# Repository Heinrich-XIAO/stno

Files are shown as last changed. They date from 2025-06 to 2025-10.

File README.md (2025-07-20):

# stno

stno is a one-handed steno keyboard with joysticks for my thumb. I wanted to make stno because I became obsessed with steno, didn't have an n-key roll over keyboard and i didnt want to keep arpegiating, and i wanted a one-handed keyboard like my other keyboards (all of them were too small for a steno layout). I wanted to use joysticks since i feel like holding two keys with one finger is awkward and wanted to minimize it, especially for the thumb.

## 🟩PCB
1751285202-wayshot

## 📐Schematic
1751285280-wayshot

## 📏CAD




## 📦BOM

| Name | Price (and Currency) | Link/source | Notes |
|---|---|---|---|
| Springs | $13.49 CAD | https://www.aliexpress.com/item/1005006171011050.html | $4.52 after welcome deal |
| TTC Neptune Switches | $27.26 USD | https://milktooth.com/products/neptune | $5.09 per pack $11.99 shipping |
| Arduino Nano ESP32 | $29.67 USD | https://store-usa.arduino.cc/products/nano-esp32 | |
| Joysticks | $21.67 CAD | https://www.amazon.com/PS5-Hall-Effect-Joystick-Replacement-2-Pack/dp/B0DN8T9KJW | $7.68 shipping + $13.99 |
| Thumbscrews | $13.99 CAD | https://www.amazon.ca/MECCANIXITY-Stainless-Thumbscrew-Appliances-Electronic/dp/B0F282TJ7D | |
| Nuts and Bolts | $13.11 CAD | https://www.amazon.ca/Walfront-Socket-Head-Button-Screws/dp/B0742DDLQ1 | this is an assortment of screws but its still somehow cheaper than some non-assortements ive found. it also means hackclub won't have to pay for 10 dollars worth of bolts every time i need a different length of bolt |
| Keycaps | $5.31 CAD | https://www.aliexpress.com/item/1005008653485944.html | 3 packs of ten $1.36 per pack |
| Heatset Inserts | $4.79 CAD | https://www.aliexpress.com/item/1005003582355741.html | m3 4mm $1.39 after welcome deal |
| Hotswap Sockets | $9.83 CAD | https://www.aliexpress.com/item/1005003913466247.html | $1.39 after welcome deal |
| PCB | $31.82 USD | JLCPCB | 

Total: $145.99 USD

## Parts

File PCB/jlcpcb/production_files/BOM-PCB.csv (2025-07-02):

Comment | Designator | Footprint | LCSC | Quantity
SK6812 | D41 | LED_SK6812_PLCC4_5.0x5.0mm_P3.2mm |  | 1
1N4148 | D5 | DIOAD753W49L380D172B |  | 1
1N4148 | D3 | DIOAD753W49L380D172B |  | 1
1N4148 | D1 | DIOAD753W49L380D172B |  | 1
1N4148 | D2 | DIOAD753W49L380D172B |  | 1
1N4148 | D18 | DIOAD753W49L380D172B |  | 1
1N4148 | D14 | DIOAD753W49L380D172B |  | 1
SK6812 | D33 | LED_SK6812_PLCC4_5.0x5.0mm_P3.2mm |  | 1
SK6812 | D31 | LED_SK6812_PLCC4_5.0x5.0mm_P3.2mm |  | 1
COM-09032 | U1 | PS4_joystick |  | 1
Arduino_Nano_ESP32 | A1 | Arduino_Nano |  | 1
SK6812 | D35 | LED_SK6812_PLCC4_5.0x5.0mm_P3.2mm |  | 1
1N4148 | D4 | DIOAD753W49L380D172B |  | 1
1N4148 | D8 | DIOAD753W49L380D172B |  | 1
1N4148 | D13 | DIOAD753W49L380D172B |  | 1
SK6812 | D34 | LED_SK6812_PLCC4_5.0x5.0mm_P3.2mm |  | 1
SK6812 | D46 | LED_SK6812_PLCC4_5.0x5.0mm_P3.2mm |  | 1
SK6812 | D37 | LED_SK6812_PLCC4_5.0x5.0mm_P3.2mm |  | 1
SK6812 | D40 | LED_SK6812_PLCC4_5.0x5.0mm_P3.2mm |  | 1
1N4148 | D10 | DIOAD753W49L380D172B |  | 1
SK6812 | D50 | LED_SK6812_PLCC4_5.0x5.0mm_P3.2mm |  | 1
1N4148 | D23 | DIOAD753W49L380D172B |  | 1
SK6812 | D38 | LED_SK6812_PLCC4_5.0x5.0mm_P3.2mm |  | 1
SK6812 | D47 | LED_SK6812_PLCC4_5.0x5.0mm_P3.2mm |  | 1
1N4148 | D19 | DIOAD753W49L380D172B |  | 1
SK6812 | D45 | LED_SK6812_PLCC4_5.0x5.0mm_P3.2mm |  | 1
1N4148 | D20 | DIOAD753W49L380D172B |  | 1
1N4148 | D21 | DIOAD753W49L380D172B |  | 1
SK6812 | D29 | LED_SK6812_PLCC4_5.0x5.0mm_P3.2mm |  | 1
1N4148 | D12 | DIOAD753W49L380D172B |  | 1
1N4148 | D24 | DIOAD753W49L380D172B |  | 1
SK6812 | D32 | LED_SK6812_PLCC4_5.0x5.0mm_P3.2mm |  | 1
SK6812 | D26 | LED_SK6812_PLCC4_5.0x5.0mm_P3.2mm |  | 1
SK6812 | D39 | LED_SK6812_PLCC4_5.0x5.0mm_P3.2mm |  | 1
SK6812 | D28 | LED_SK6812_PLCC4_5.0x5.0mm_P3.2mm |  | 1
SK6812 | D42 | LED_SK6812_PLCC4_5.0x5.0mm_P3.2mm |  | 1
SK6812 | D44 | LED_SK6812_PLCC4_5.0x5.0mm_P3.2mm |  | 1
COM-09032 | U2 | PS4_joystick |  | 1
1N4148 | D11 | DIOAD753W49L380D172B |  | 1
SK6812 | D43 | LED_SK6812_PLCC4_5.0x5.0mm_P3.2mm |  | 1
1N4148 | D15 | DIOAD753W49L380D172B |  | 1
SK6812 | D30 | LED_SK6812_PLCC4_5.0x5.0mm_P3.2mm |  | 1
1N4148 | D9 | DIOAD753W49L380D172B |  | 1
1N4148 | D7 | DIOAD753W49L380D172B |  | 1
SK6812 | D48 | LED_SK6812_PLCC4_5.0x5.0mm_P3.2mm |  | 1
SK6812 | D27 | LED_SK6812_PLCC4_5.0x5.0mm_P3.2mm |  | 1
SK6812 | D36 | LED_SK6812_PLCC4_5.0x5.0mm_P3.2mm |  | 1
SK6812 | D49 | LED_SK6812_PLCC4_5.0x5.0mm_P3.2mm |  | 1
1N4148 | D6 | DIOAD753W49L380D172B |  | 1
1N4148 | D17 | DIOAD753W49L380D172B |  | 1
1N4148 | D25 | DIOAD753W49L380D172B |  | 1
1N4148 | D16 | DIOAD753W49L380D172B |  | 1
1N4148 | D22 | DIOAD753W49L380D172B |  | 1
SW_Push | SW13 | hotswap |  | 1
SW_Push | SW9 | hotswap |  | 1
SW_Push | SW24 | hotswap |  | 1
SW_Push | SW7 | hotswap |  | 1
SW_Push | SW19 | hotswap |  | 1
SW_Push | SW3 | hotswap |  | 1
SW_Push | SW11 | hotswap |  | 1
SW_Push | SW17 | hotswap |  | 1
SW_Push | SW26 | hotswap |  | 1
SW_Push | SW2 | hotswap |  | 1
SW_Push | SW12 | hotswap |  | 1
SW_Push | SW14 | hotswap |  | 1
SW_Push | SW5 | hotswap |  | 1
SW_Push | SW6 | hotswap |  | 1
SW_Push | SW22 | hotswap |  | 1
SW_Push | SW4 | hotswap |  | 1
SW_Push | SW25 | hotswap |  | 1
SW_Push | SW20 | hotswap |  | 1
SW_Push | SW23 | hotswap |  | 1
SW_Push | SW10 | hotswap |  | 1
SW_Push | SW21 | hotswap |  | 1
SW_Push | SW15 | hotswap |  | 1
SW_Push | SW18 | hotswap |  | 1
SW_Push | SW8 | hotswap |  | 1
SW_Push | SW16 | hotswap |  | 1

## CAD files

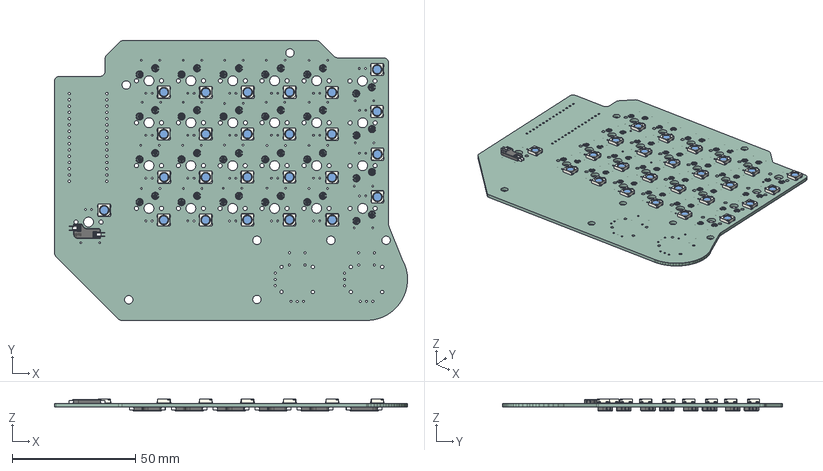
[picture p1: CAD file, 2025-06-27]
PCB/PCB.step
143.2 x 113.5 x 4.88 mm
LED_SK6812_PLCC4_5.0x5.0mm_P3.2mm x 25
Contact x 50
PCB_PCB

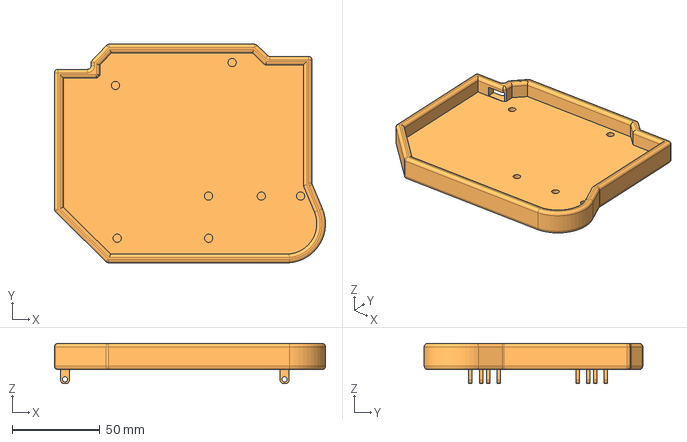
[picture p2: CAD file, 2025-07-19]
production/body.step
154.3 x 124.4 x 23.0 mm

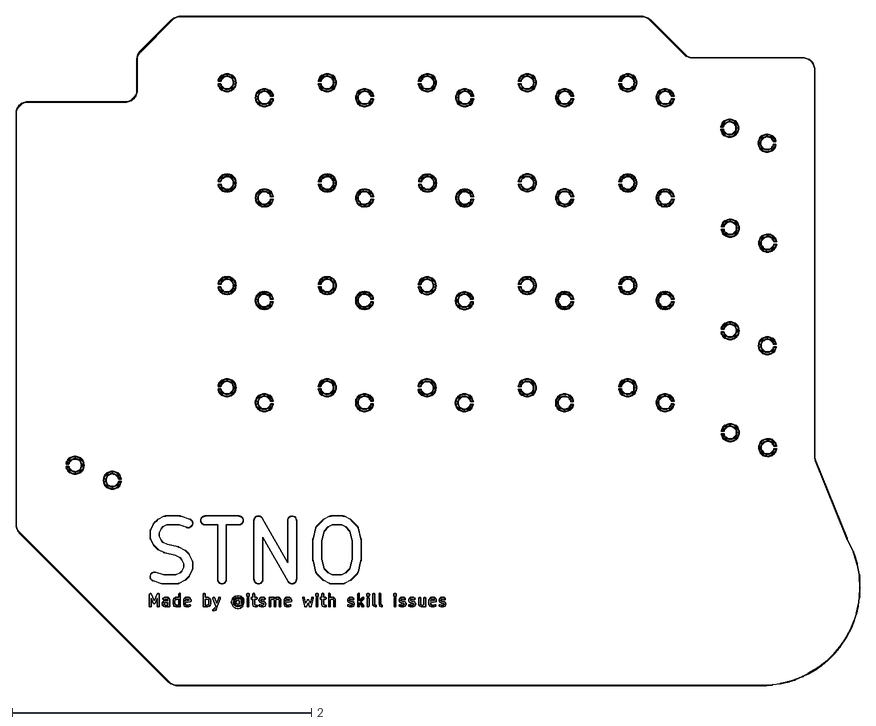
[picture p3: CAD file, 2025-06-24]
PCB/PCB-Edge_Cuts.dxf
5.64 x 4.47

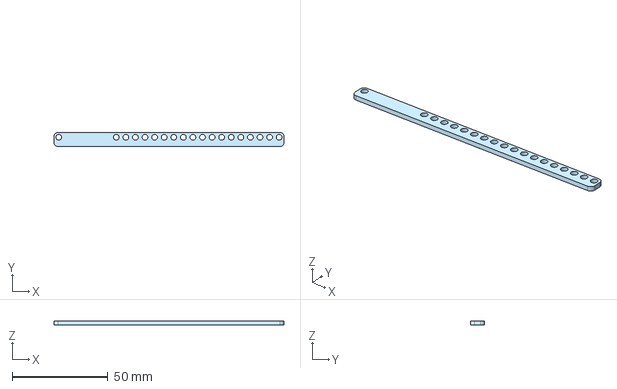
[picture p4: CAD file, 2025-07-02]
production/tent_adjustable_part.step
120.0 x 7.30 x 2.00 mm

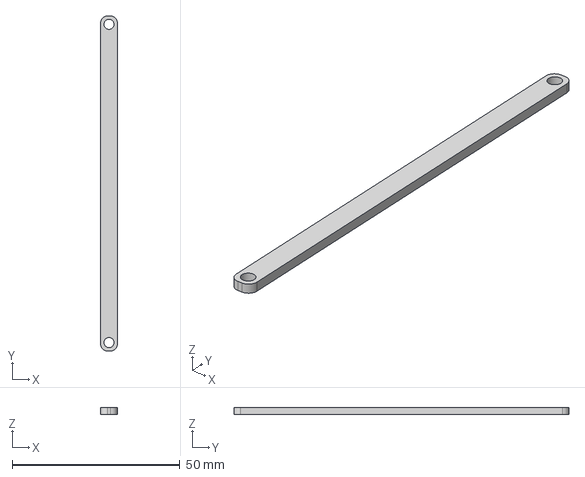
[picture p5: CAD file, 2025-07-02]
production/tent_non_adjustable_part.step
5.00 x 100.0 x 2.00 mm

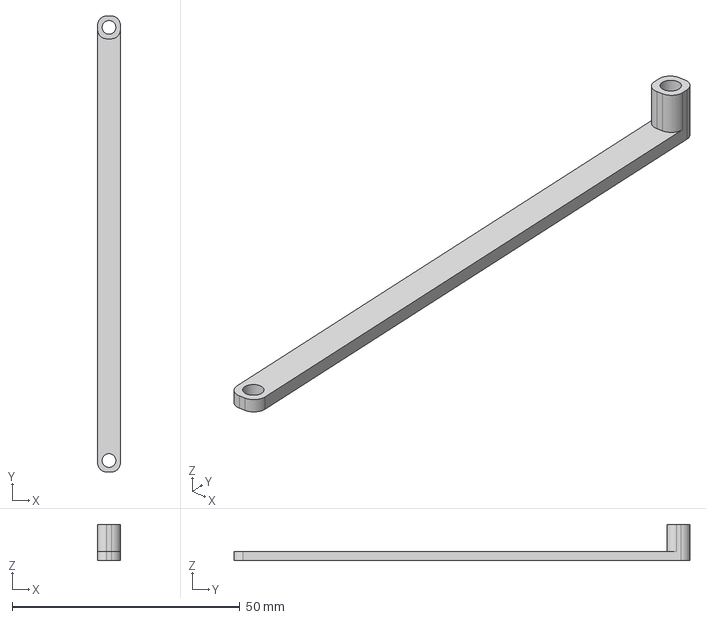
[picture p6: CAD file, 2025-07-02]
production/tent_non_adjustable_with_thing_at_end.step
5.00 x 100.0 x 8.00 mm

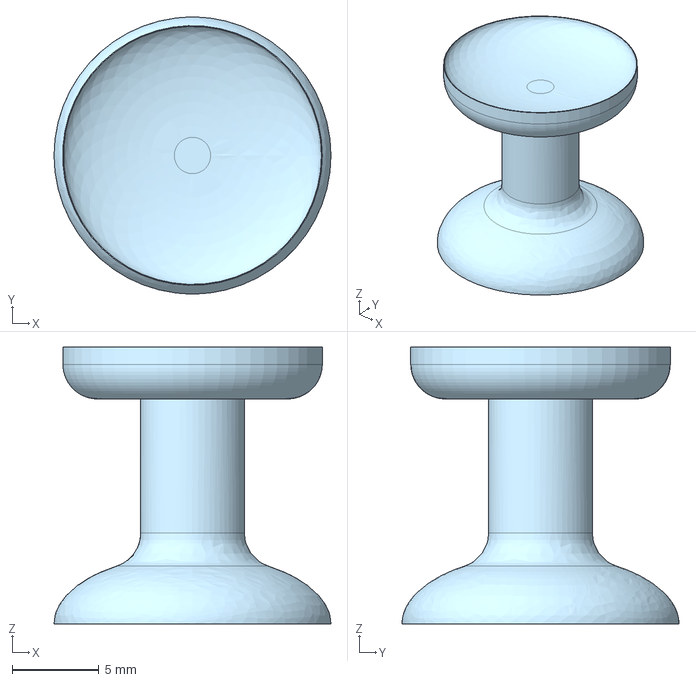
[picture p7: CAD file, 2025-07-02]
production/joystick.step
16.0 x 16.0 x 16.0 mm

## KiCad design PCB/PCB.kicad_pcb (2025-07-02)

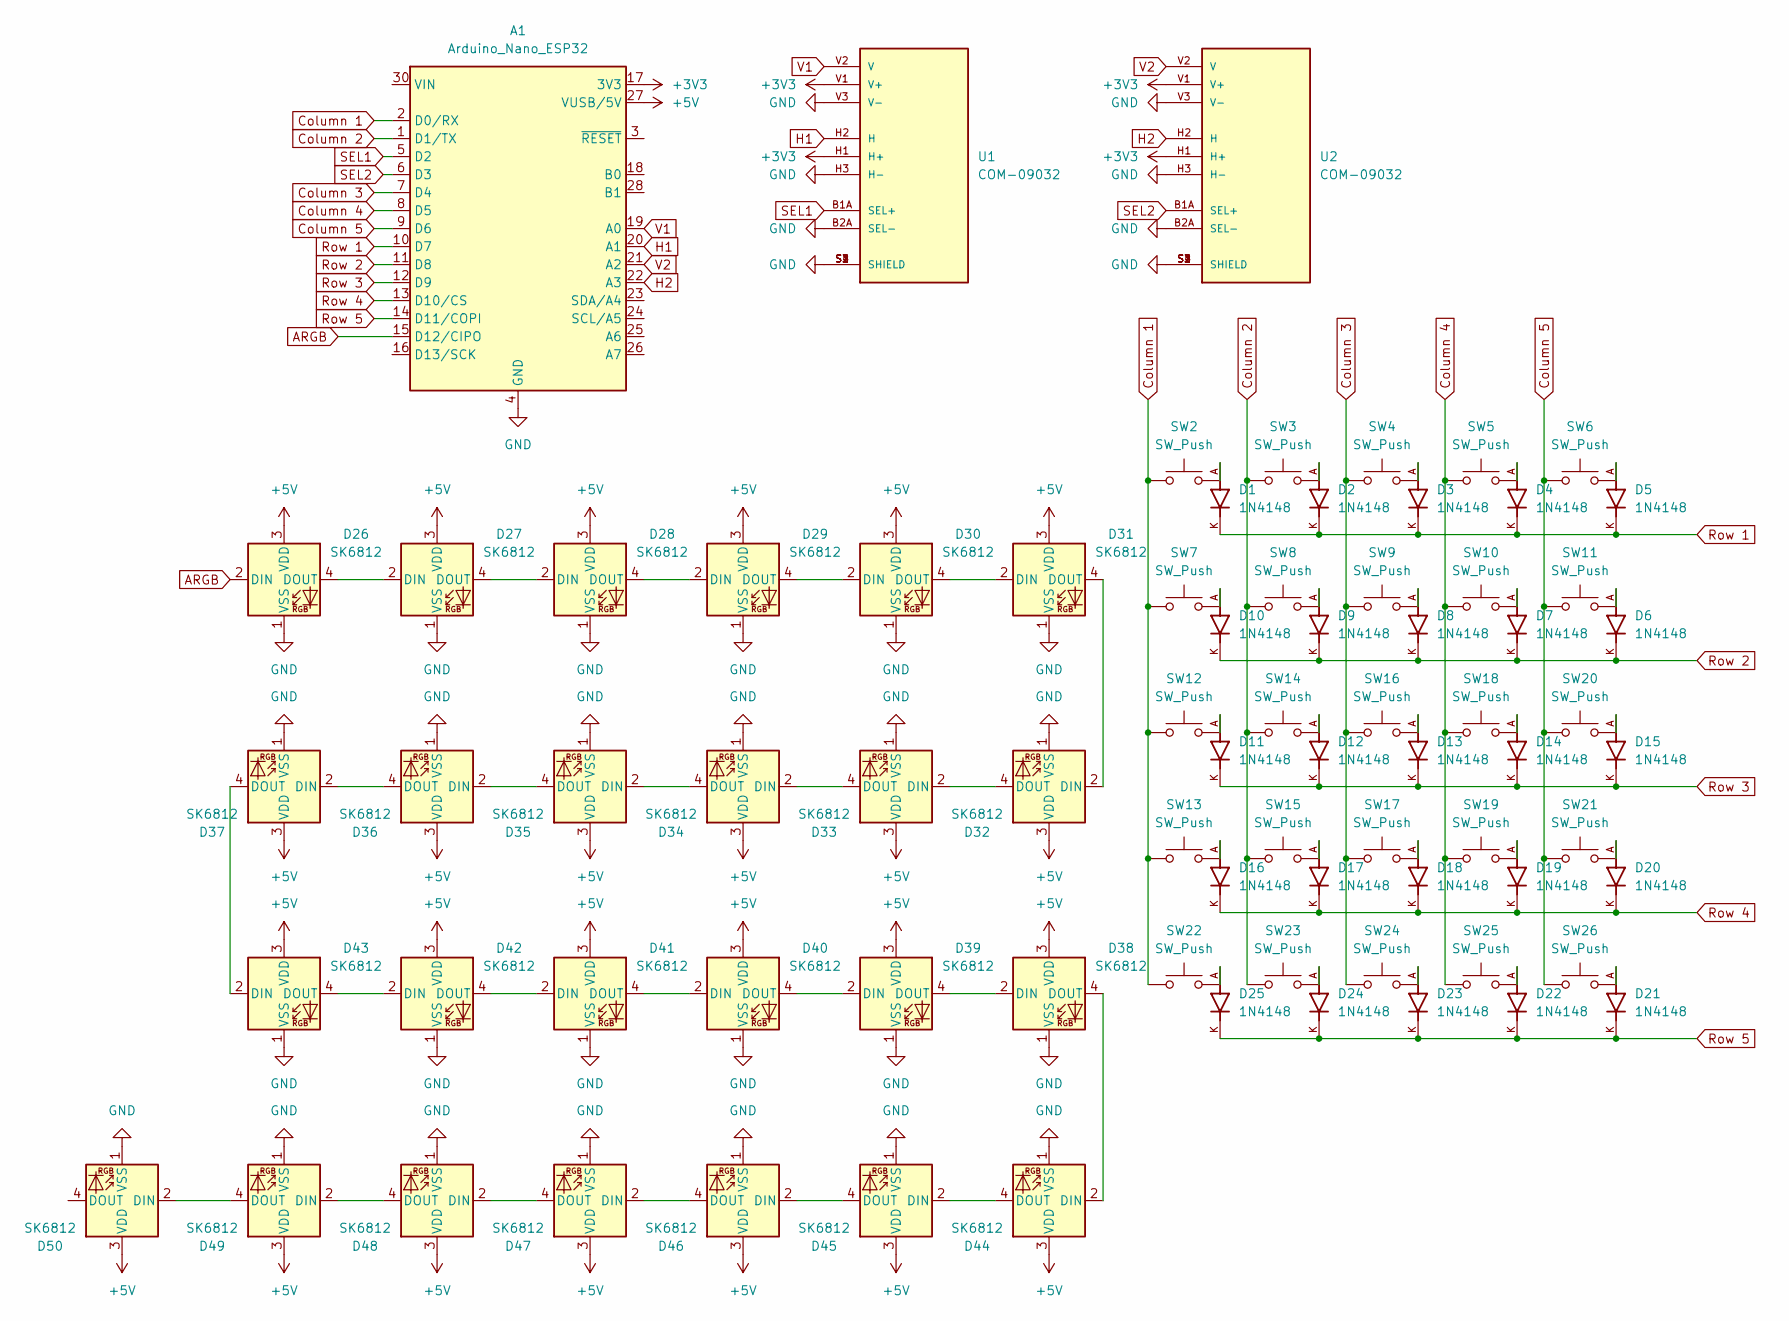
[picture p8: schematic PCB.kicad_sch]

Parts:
A1: Arduino_Nano_ESP32; Arduino_Nano
D1, D2, D3, D4, D5, D6, D7, D8, D9, D10, D11, D12, D13, D14, D15, D16, D17, D18, D19, D20, D21, D22, D23, D24, D25: 1N4148; DIOAD753W49L380D172B; PARTREV 5
D26, D27, D28, D29, D30, D31, D32, D33, D34, D35, D36, D37, D38, D39, D40, D41, D42, D43, D44, D45, D46, D47, D48, D49, D50: SK6812; LED_SK6812_PLCC4_5.0x5.0mm_P3.2mm
SW2, SW3, SW4, SW5, SW6, SW7, SW8, SW9, SW10, SW11, SW12, SW13, SW14, SW15, SW16, SW17, SW18, SW19, SW20, SW21, SW22, SW23, SW24, SW25, SW26: SW_Push; hotswap
U1, U2: COM-09032; PS4_joystick; PARTREV N/A

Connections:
+3V3: A1.17 (3V3), U1.H1 (H+), U1.V1 (V+), U2.H1 (H+), U2.V1 (V+)
+5V: A1.27 (VUSB/5V), D26.3 (VDD), D27.3 (VDD), D28.3 (VDD), D29.3 (VDD), D30.3 (VDD), D31.3 (VDD), D32.3 (VDD), D33.3 (VDD), D34.3 (VDD), D35.3 (VDD), D36.3 (VDD), D37.3 (VDD), D38.3 (VDD), D39.3 (VDD), D40.3 (VDD), D41.3 (VDD), D42.3 (VDD), D43.3 (VDD), D44.3 (VDD), D45.3 (VDD), D46.3 (VDD), D47.3 (VDD), D48.3 (VDD), D49.3 (VDD), D50.3 (VDD)
ARGB: A1.15 (D12/CIPO), D26.2 (DIN)
Column 1: A1.2 (D0/RX), SW2.1, SW7.1, SW12.1, SW13.1, SW22.1
Column 2: A1.1 (D1/TX), SW3.1, SW8.1, SW14.1, SW15.1, SW23.1
Column 3: A1.7 (D4), SW4.1, SW9.1, SW16.1, SW17.1, SW24.1
Column 4: A1.8 (D5), SW5.1, SW10.1, SW18.1, SW19.1, SW25.1
Column 5: A1.9 (D6), SW6.1, SW11.1, SW20.1, SW21.1, SW26.1
GND: A1.4 (GND), A1.29 (GND), D26.1 (VSS), D27.1 (VSS), D28.1 (VSS), D29.1 (VSS), D30.1 (VSS), D31.1 (VSS), D32.1 (VSS), D33.1 (VSS), D34.1 (VSS), D35.1 (VSS), D36.1 (VSS), D37.1 (VSS), D38.1 (VSS), D39.1 (VSS), D40.1 (VSS), D41.1 (VSS), D42.1 (VSS), D43.1 (VSS), D44.1 (VSS), D45.1 (VSS), D46.1 (VSS), D47.1 (VSS), D48.1 (VSS), D49.1 (VSS), D50.1 (VSS), U1.B2A (SEL-), U1.H3 (H-), U1.S1 (SHIELD), U1.S2 (SHIELD), U1.S3 (SHIELD), U1.S4 (SHIELD), U1.V3 (V-), U2.B2A (SEL-), U2.H3 (H-), U2.S1 (SHIELD), U2.S2 (SHIELD), U2.S3 (SHIELD), U2.S4 (SHIELD), U2.V3 (V-)
H1: A1.20 (A1), U1.H2 (H)
H2: A1.22 (A3), U2.H2 (H)
unnamed: D1.A, SW2.2
unnamed: D2.A, SW3.2
unnamed: D3.A, SW4.2
unnamed: D4.A, SW5.2
unnamed: D5.A, SW6.2
unnamed: D6.A, SW11.2
unnamed: D7.A, SW10.2
unnamed: D8.A, SW9.2
unnamed: D9.A, SW8.2
unnamed: D10.A, SW7.2
unnamed: D11.A, SW12.2
unnamed: D12.A, SW14.2
unnamed: D13.A, SW16.2
unnamed: D14.A, SW18.2
unnamed: D15.A, SW20.2
unnamed: D16.A, SW13.2
unnamed: D17.A, SW15.2
unnamed: D18.A, SW17.2
unnamed: D19.A, SW19.2
unnamed: D20.A, SW21.2
unnamed: D21.A, SW26.2
unnamed: D22.A, SW25.2
unnamed: D23.A, SW24.2
unnamed: D24.A, SW23.2
unnamed: D25.A, SW22.2
unnamed: D26.4 (DOUT), D27.2 (DIN)
unnamed: D27.4 (DOUT), D28.2 (DIN)
unnamed: D28.4 (DOUT), D29.2 (DIN)
unnamed: D29.4 (DOUT), D30.2 (DIN)
unnamed: D30.4 (DOUT), D31.2 (DIN)
unnamed: D31.4 (DOUT), D32.2 (DIN)
unnamed: D32.4 (DOUT), D33.2 (DIN)
unnamed: D33.4 (DOUT), D34.2 (DIN)
unnamed: D34.4 (DOUT), D35.2 (DIN)
unnamed: D35.4 (DOUT), D36.2 (DIN)
unnamed: D36.4 (DOUT), D37.2 (DIN)
unnamed: D37.4 (DOUT), D43.2 (DIN)
unnamed: D38.2 (DIN), D39.4 (DOUT)
unnamed: D38.4 (DOUT), D44.2 (DIN)
unnamed: D39.2 (DIN), D40.4 (DOUT)
unnamed: D40.2 (DIN), D41.4 (DOUT)
unnamed: D41.2 (DIN), D42.4 (DOUT)
unnamed: D42.2 (DIN), D43.4 (DOUT)
unnamed: D44.4 (DOUT), D45.2 (DIN)
unnamed: D45.4 (DOUT), D46.2 (DIN)
unnamed: D46.4 (DOUT), D47.2 (DIN)
unnamed: D47.4 (DOUT), D48.2 (DIN)
unnamed: D48.4 (DOUT), D49.2 (DIN)
unnamed: D49.4 (DOUT), D50.2 (DIN)
Row 1: A1.10 (D7), D1.K, D2.K, D3.K, D4.K, D5.K
Row 2: A1.11 (D8), D6.K, D7.K, D8.K, D9.K, D10.K
Row 3: A1.12 (D9), D11.K, D12.K, D13.K, D14.K, D15.K
Row 4: A1.13 (D10/CS), D16.K, D17.K, D18.K, D19.K, D20.K
Row 5: A1.14 (D11/COPI), D21.K, D22.K, D23.K, D24.K, D25.K
SEL1: A1.5 (D2), U1.B1A (SEL+)
SEL2: A1.6 (D3), U2.B1A (SEL+)
V1: A1.19 (A0), U1.V2 (V)
V2: A1.21 (A2), U2.V2 (V)

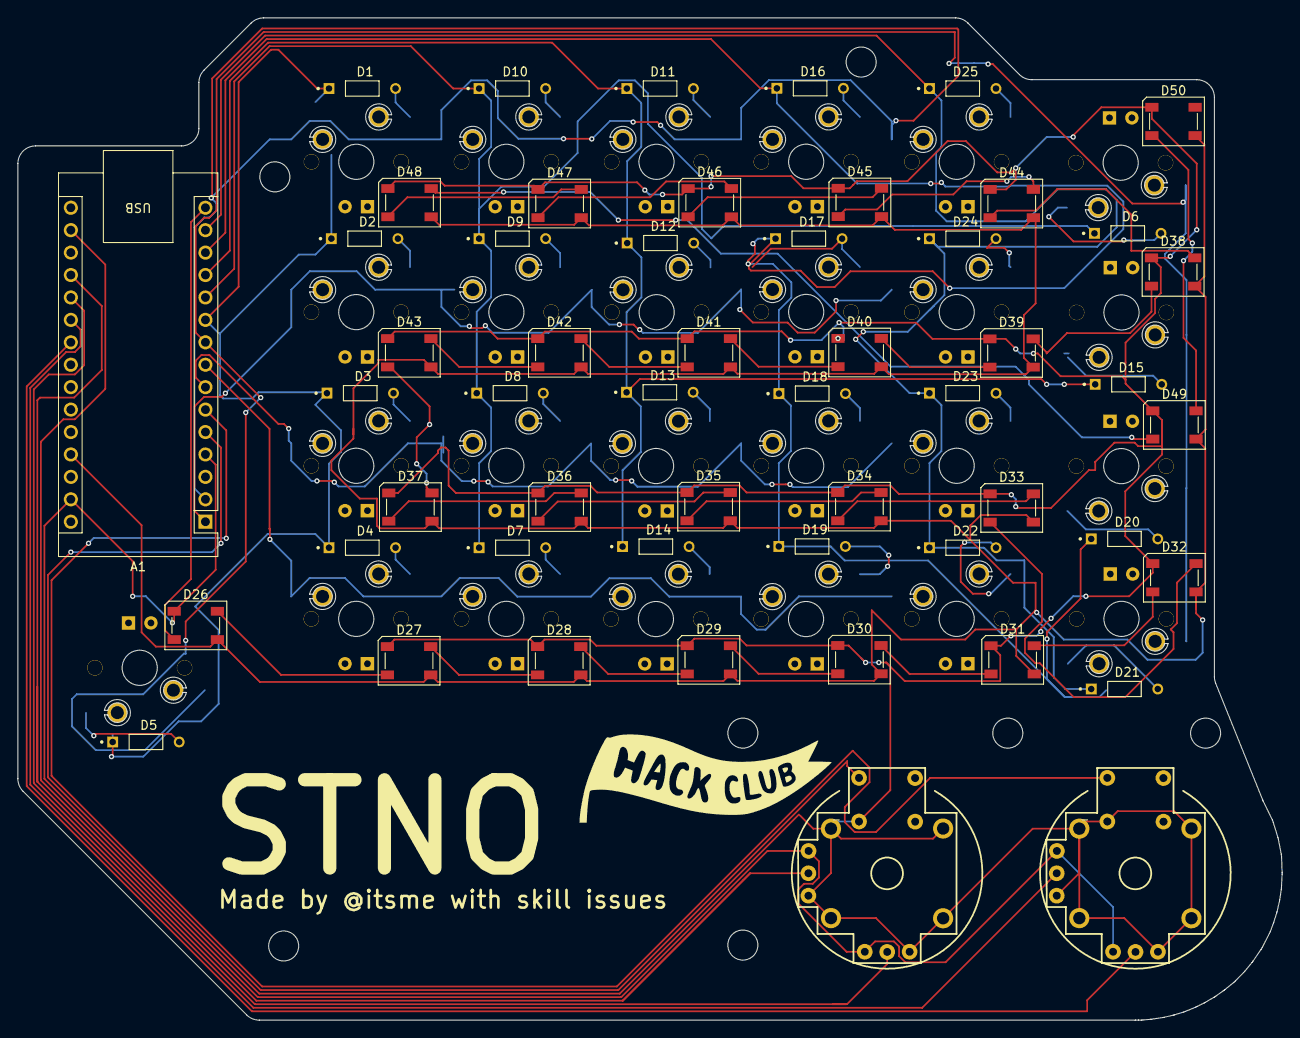
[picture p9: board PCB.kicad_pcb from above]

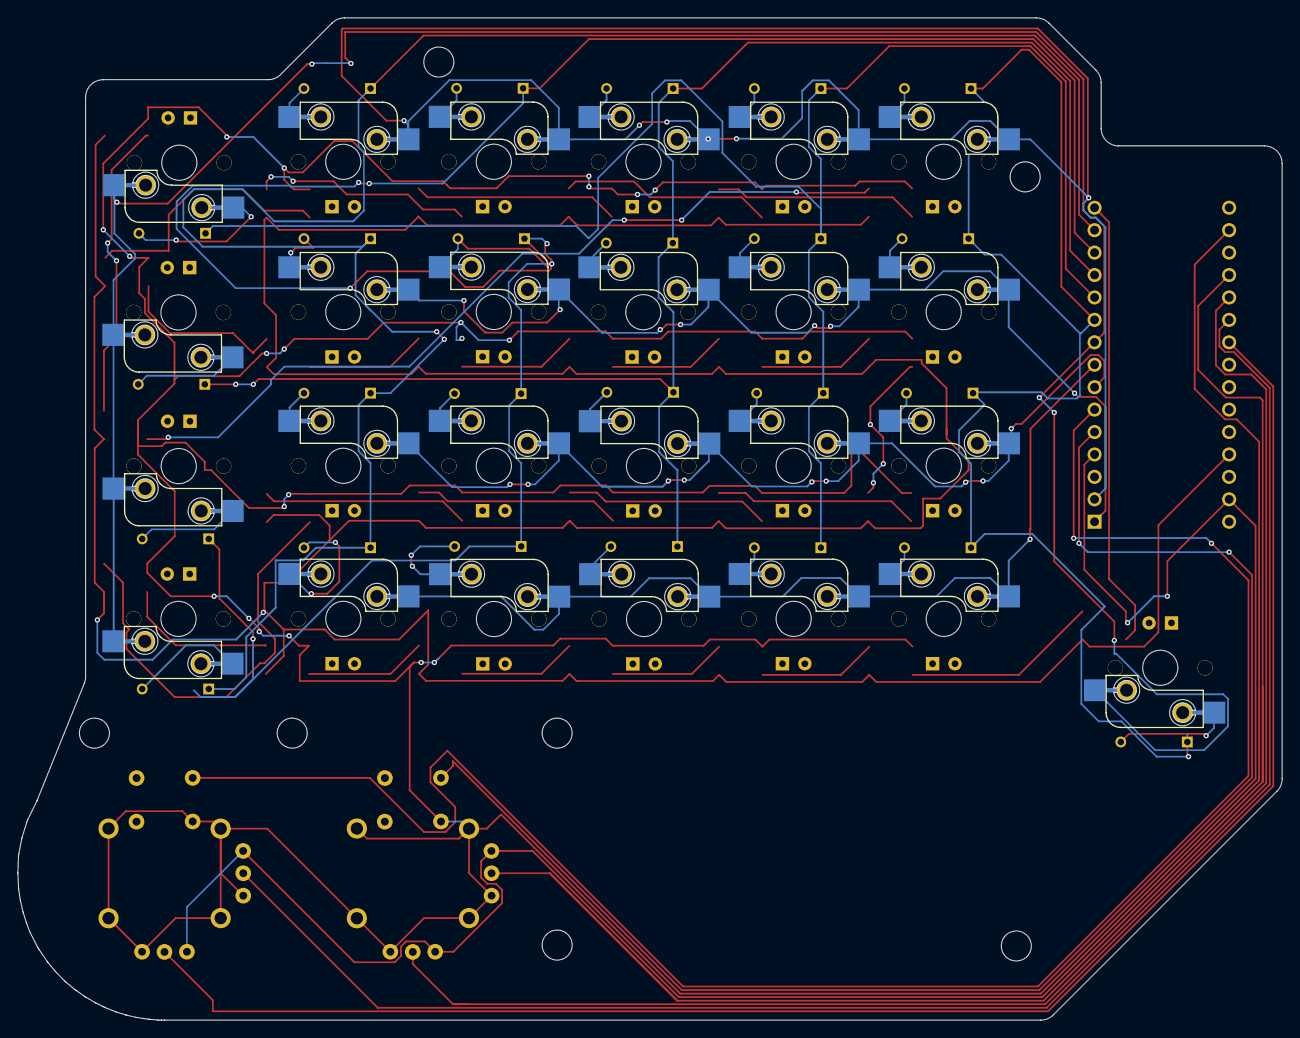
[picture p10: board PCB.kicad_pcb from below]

Board: 2 copper layers, 143.2 x 113.5 mm, 78 parts (25 on the bottom side), 69 nets.

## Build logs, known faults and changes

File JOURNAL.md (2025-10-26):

<!--
  ===================    !!READ THIS NOTICE!!   ====================
  DO NOT edit this file manually. Your changes WILL BE OVERWRITTEN!
  This journal is auto generated and updated by Hack Club Blueprint.
  To edit this file, please edit your journal entries on Blueprint.
  ==================================================================
-->

## 10/26/2025 - Finished soldering everything  

I finished soldering everything to the PCB.



it wasnt too eventful, but i did have to switch some of the hotswap sockets around since i soldered them the wrong way, and i guess i also had to solderthe xiao really weirdly since i didn't have headers and idnt want to smd solder it

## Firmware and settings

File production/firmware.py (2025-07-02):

import board
import math
from kmk.kmk_keyboard import KMKKeyboard
from kmk.keys import KC
from kmk.modules.layers import Layers
from kmk.modules.hid import HIDModes
from kmk.hid import HIDKeycode
from kmk.modules.analog import Analog
from kmk.modules.steno import Steno
from kmk.modules.mouse_keys import MouseKeys

keyboard = KMKKeyboard()
keyboard.modules.append(MouseKeys())
keyboard.modules.append(Layers())
keyboard.modules.append(Steno())
keyboard.modules.append(HIDModes())
# Analog joystick module
analog = Analog()
keyboard.modules.append(analog)



def transform_grid(input_grid, extra_key):
    transformed = [[None for _ in range(5)] for _ in range(5)]

    for col in range(5):
        for row in range(4):
            transformed[col][row] = input_grid[row][col]

    for row in range(4):
        transformed[4][row] = input_grid[row][5]

    transformed[4][4] = extra_key

    flat_output = [transformed[r][c] for r in range(5) for c in range(5)]
    return flat_output



keyboard.col_pins = (board.D0, board.D1, board.D4, board.D5, board.D6)  # 5 cols
keyboard.row_pins = (board.D7, board.D8, board.D9, board.D10, board.D11)  # 5 rows

keyboard.diode_orientation = keyboard.DIODE_COL2ROW

layer0 = [
    KC.F,    KC.P,   KC.L,   KC.T,   KC.D,
    KC.R,     KC.B,    KC.G,    KC.S,    KC.Z,
    KC.S,     KC.T,    KC.P,    KC.H,    KC.J,
    KC.ASTR,  KC.K,    KC.W,    KC.R,    KC.N,
    KC.TRNS,KC.MB_LMB,KC.MB_RMB,KC.MB_MMB,KC.TRNS,
]

keyboard.keymap = [
    transform_grid(layer0, KC.TRNS),
]


# Constants
V_PIN = board.A0
H_PIN = board.A1
DEADZONE = 0.2  # to ignore small wobbles

# This maps 16 compass directions to AOEU chords
SECTOR_CHORDS = [
    ('O',),               # 0   → East
    ('A','O'),            # 1   → ENE
    ('A','O','E'),        # 2   → NE
    ('O','E'),            # 3   → NNE
    ('E',),               # 4   → South
    ('A','E'),            # 5   → SSE
    ('A','E','U'),        # 6   → SE
    ('E','U'),            # 7   → ESE
    ('U',),               # 8   → West
    ('A','U'),            # 9   → WNW
    ('A','O','U'),        # 10  → NW
    ('O','U'),            # 11  → NNW
    ('A',),               # 12  → North
    ('A','O','E','U'),    # 13  → NNE wraparound
    ('O','E','U'),        # 14  → ESE wraparound
    ('A','U','E'),        # 15  → SSE wraparound
]


# Mapping from steno letter to HIDKeycode used by Plover
STENO_KEYCODES = {
    'A': HIDKeycode.S,
    'O': HIDKeycode.D,
    'E': HIDKeycode.F,
    'U': HIDKeycode.J,
}

def get_steno_chord_from_joystick():
    v = analog.analog_read(V_PIN)  # vertical axis
    h = analog.analog_read(H_PIN)  # horizontal axis

    # Normalize to -1.0 ... 1.0
    v = (v - 32768) / 32768
    h = (h - 32768) / 32768

    magnitude = math.sqrt(h*h + v*v)
    if magnitude < DEADZONE:
        return []  # don't send anything

    angle = math.atan2(-v, h)  # invert v to treat upward as +Y
    angle_deg = math.degrees(angle)
    angle_deg = (angle_deg + 360) % 360

    sector = int((angle_deg + 11.25) // 22.5) % 16
    chord = SECTOR_CHORDS[sector]
    return [STENO_KEYCODES[c] for c in chord if c in STENO_KEYCODES]

def before_matrix_scan():
    chord = get_steno_chord_from_joystick()
    if chord:
        keyboard.send_hid(chord)

keyboard.before_matrix_scan = before_matrix_scan


if __name__ == '__main__':
    keyboard.go()

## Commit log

2025-06-21 schemaitc done currently working on pcb
    [PCB.kicad_sch]
2025-06-22 made pcb
    [PCB.kicad_pcb]
2025-06-22 get rid of lock files
    [PCB.kicad_pcb]
2025-06-22 fix edge cuts layer
    [PCB-Edge_Cuts.dxf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]
2025-06-22 move text to the right layer and fix the edge cuts
    [PCB.kicad_pcb]
2025-06-23 whoops, i used the radius instead of the diametre and the circles were twice as big
    [PCB.kicad_pcb]
2025-06-24 fix the joystick footprint
    [PCB-Edge_Cuts.dxf, PCB.kicad_pcb, PCB.kicad_sch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]
2025-06-27 put all the hotswap switches on the right side
    [PCB.kicad_pcb]
2025-06-27 hotswap switches fixed
    [PCB.kicad_pcb, PCB.kicad_sch, PCB.step]
2025-06-28 ajouter des empreintes pour les touches, les diodes, et le microcontrôleur
    [PCB.kicad_pcb]
2025-06-30 pcb price added
2025-07-02 quickly made journal entry
    [BOM-PCB.csv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]
2025-07-02 cad files
    [body.step, joystick.step, tent_adjustable_part.step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]
2025-07-19 bom b in table
2025-07-19 prod folder
    [body.step, joystick.step, tent_adjustable_part.step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]
2025-07-20 Update bom.csv to fix formatting
    [bom.csv]
2025-07-20 Update bom.csv to fix formatting (again)
    [bom.csv]
2025-07-20 Update bom.csv i think i finally fixed the formatting
    [bom.csv]
2025-07-20 Update bom.csv i fucking hate csv
    [bom.csv]
2025-07-20 Update bom.csv wtf
    [bom.csv]
2025-07-20 Update README.md to use shit from bom.csv instead of crappy bom converted from list by chatccp (deepseek)
